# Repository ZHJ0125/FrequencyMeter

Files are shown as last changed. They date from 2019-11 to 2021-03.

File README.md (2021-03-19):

# FrequencyMeter
使用 Altium Designer 设计一款频率计

# Project Gallery
> 
> 1. Schematic
>

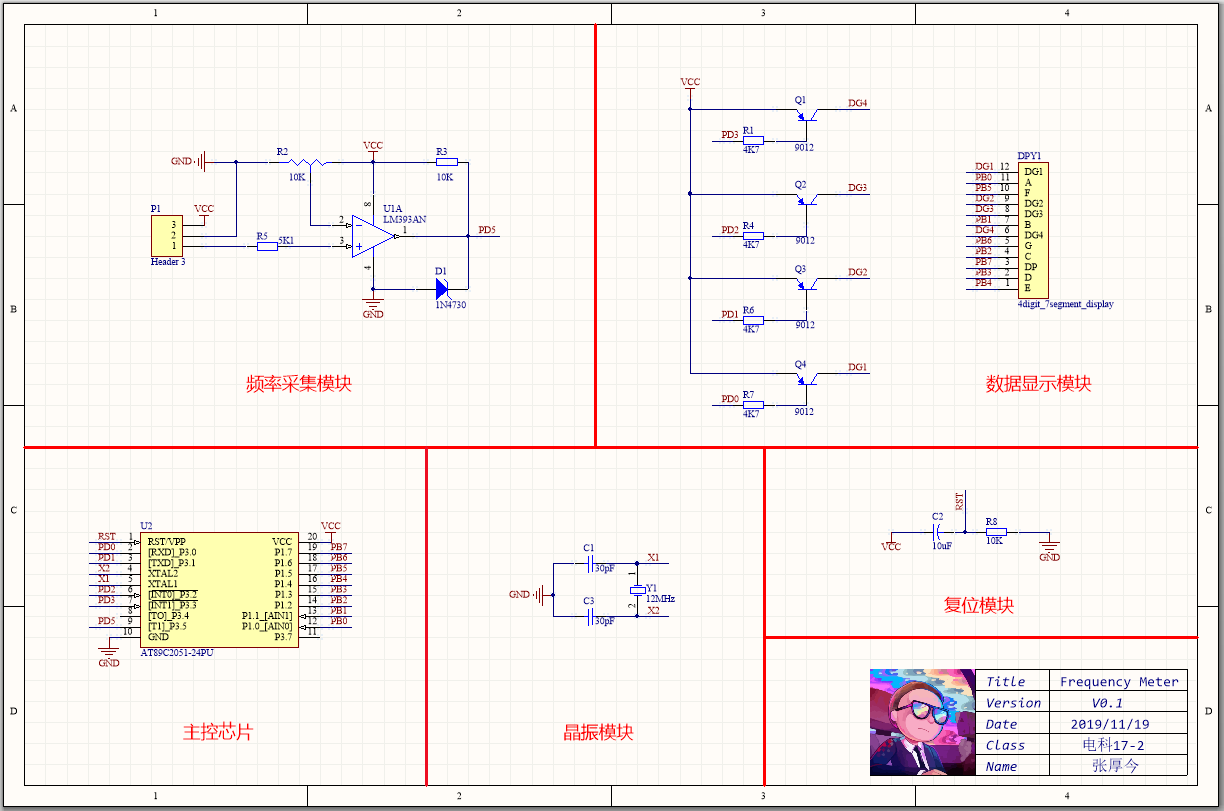
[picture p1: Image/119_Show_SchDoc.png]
119_Show_SchDoc


>
> 2. PCB Circuit
> 

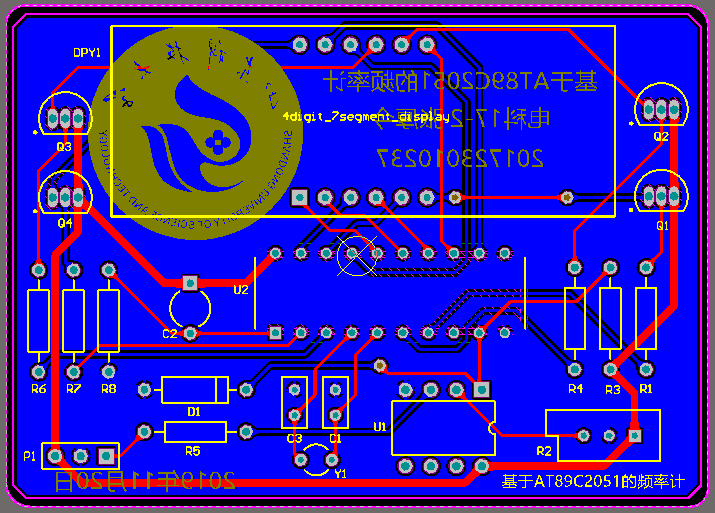
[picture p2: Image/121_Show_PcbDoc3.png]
121_Show_PcbDoc3


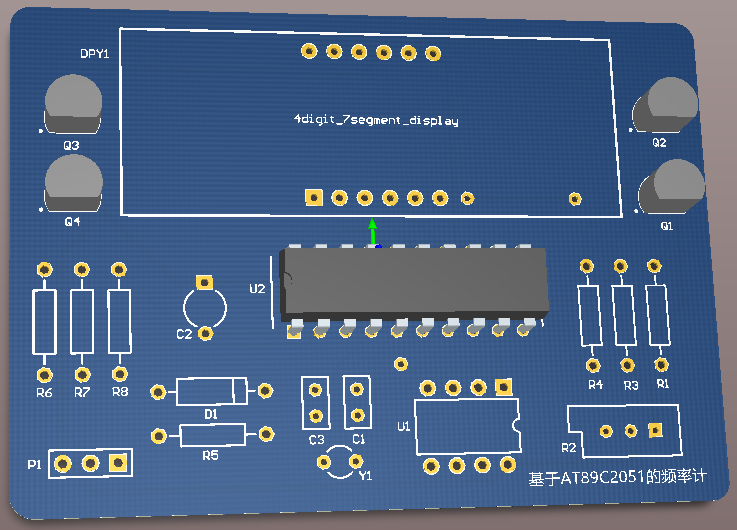
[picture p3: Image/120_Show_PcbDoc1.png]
120_Show_PcbDoc1


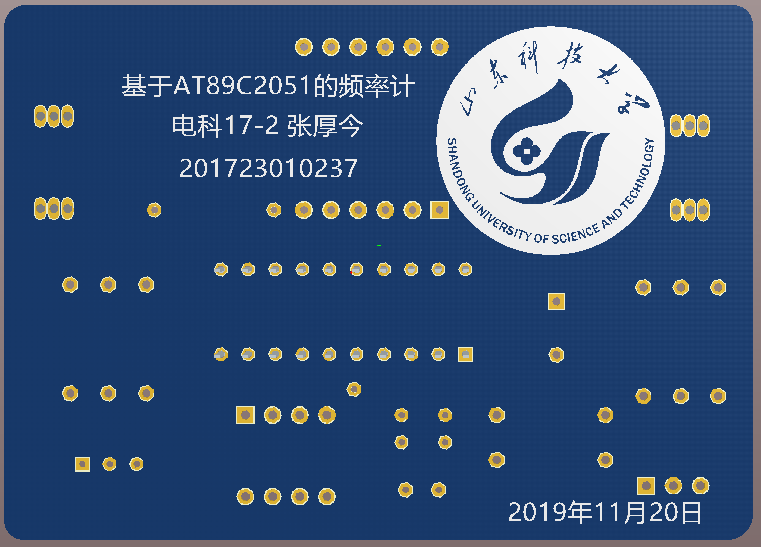
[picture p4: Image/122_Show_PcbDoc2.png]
122_Show_PcbDoc2


> 
> 3. Real object
> 

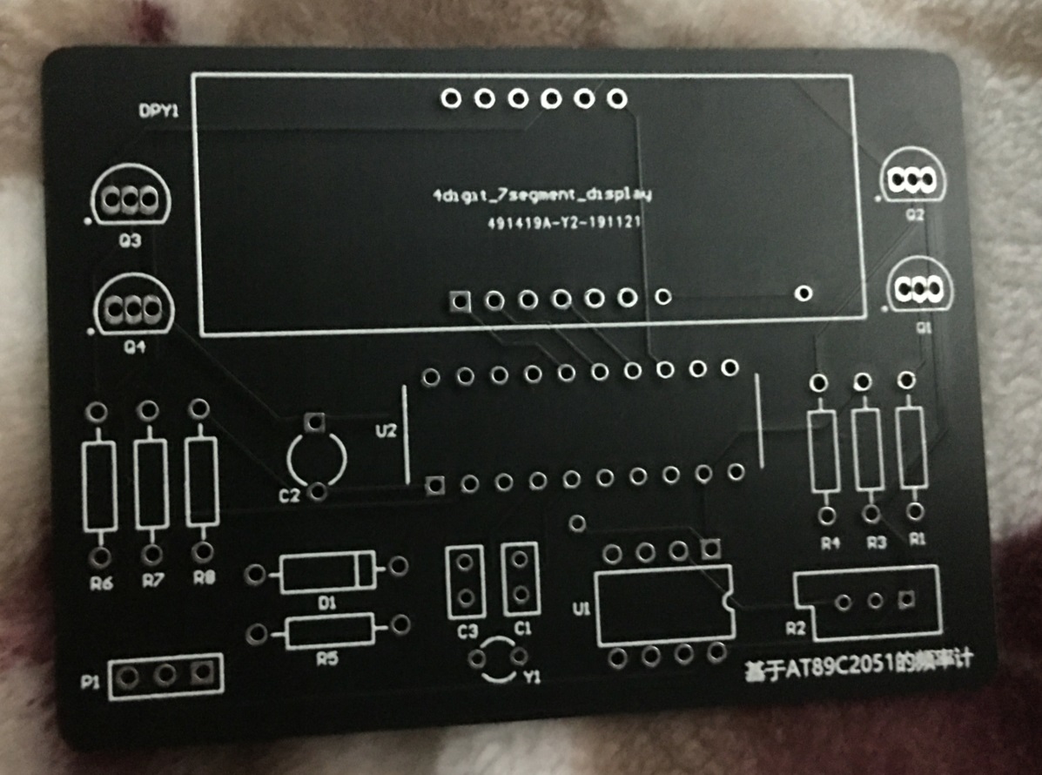
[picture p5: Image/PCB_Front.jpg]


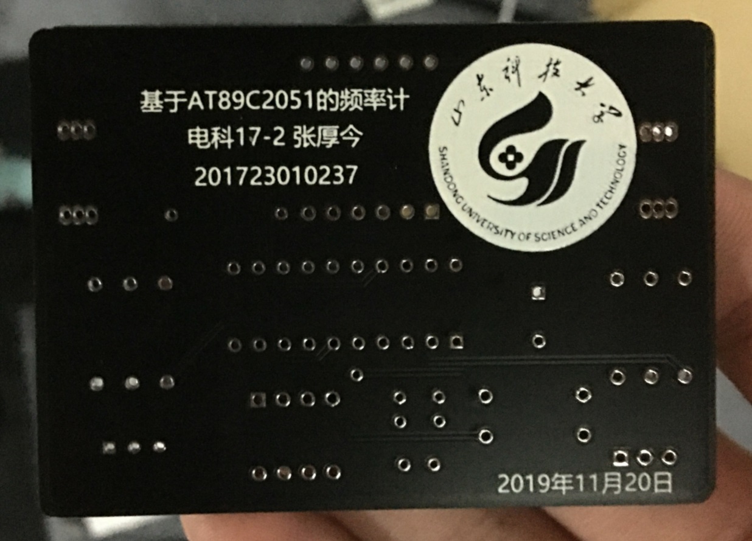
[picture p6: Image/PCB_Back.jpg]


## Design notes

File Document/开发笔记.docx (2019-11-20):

一、绘制原理图

1.1 新建工程

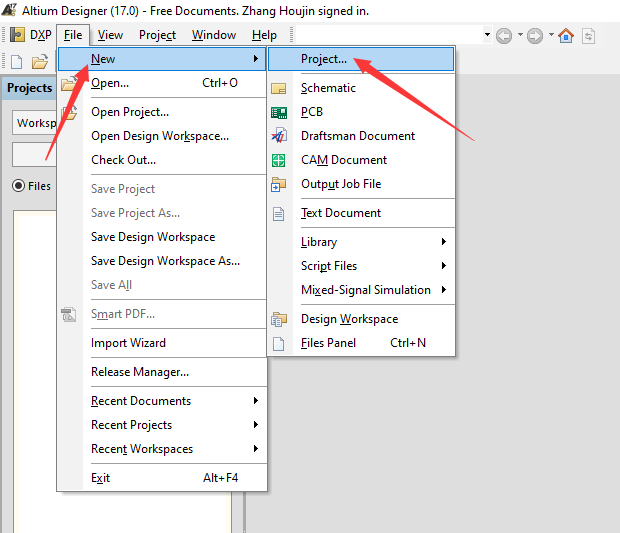
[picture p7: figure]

图1.1 新建项目

图1.2 新建工程文件

新建原理图文件

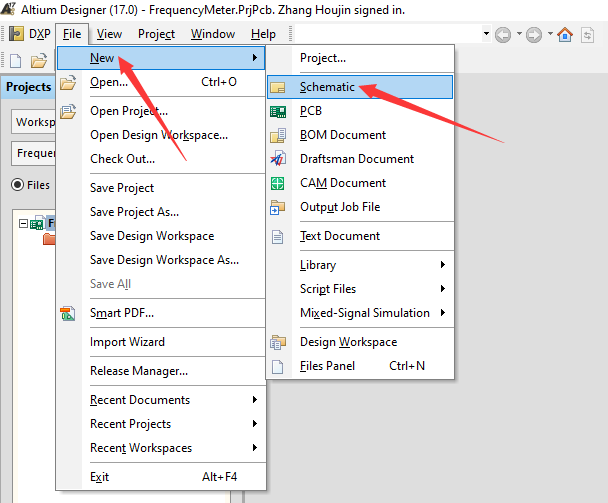
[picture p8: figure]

图1.3 创建原理图文件

图1.4原理图路径

1.2 绘制原理图

1.2.1 主控芯片

本次项目我准备全部使用网上下载的原理图库和PCB库，不再自己设计。因此首先去网上查找相关的库文件。

主控芯片使用AT89C2051芯片，20引脚，我在网上找了一些，但没有找到非常合适的，只找到了相似的.epw格式的元件库 (https://componentsearchengine.com/AT89C2051-24PU/Microchip)。Ewp格式原件经过格式转换 (https://www.samacsys.com/altium-designer-library-instructions/)即可得到AD软件可以使用的.SchLib原理图库和.PcbLib原件库。

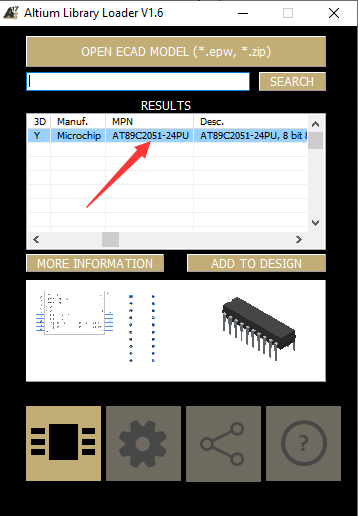
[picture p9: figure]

图1.5 文件格式转换

文件转换完成后，会在本地生成相应的库文件，里面包含此原件的原理图和封装。

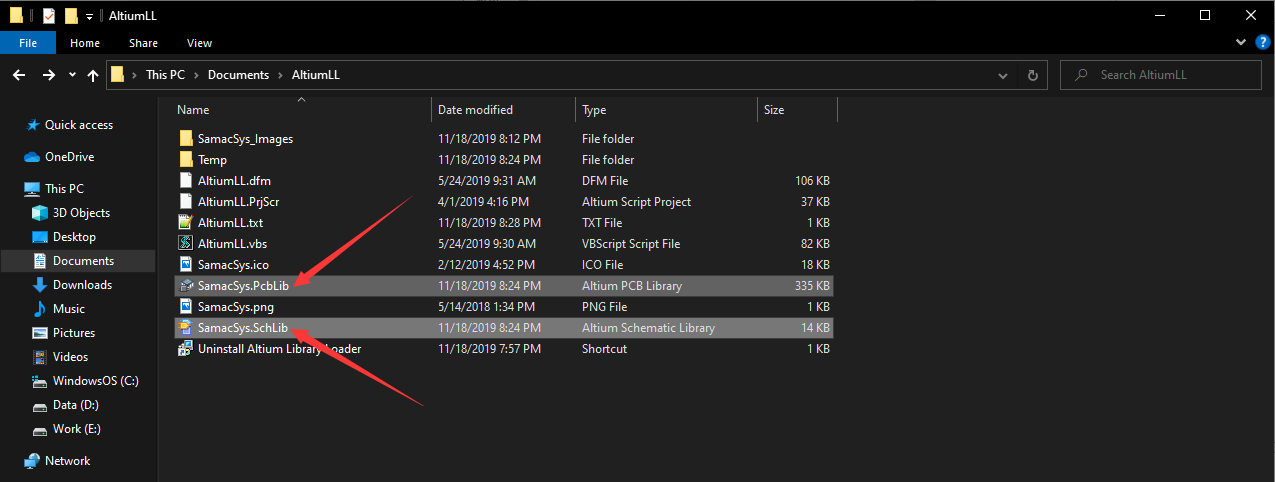
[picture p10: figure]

图1.6 原件封装库

现在把AT89C2051的原理图文件拖到原理图中就可以了。

1.2.2 数码管芯片

本次PCB使用到了四位一体数码管，我在网上找了很久都没找到合适的，于是决定自己画一个。先画原理图。

（1）原理图绘制

首先在原理图库中创建一个组件，命名为“4digit_7segment_display”。

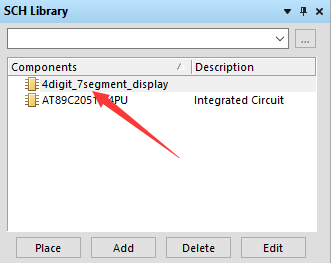
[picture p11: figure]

接着就是在编辑面板中画图了，画完之后长这样：

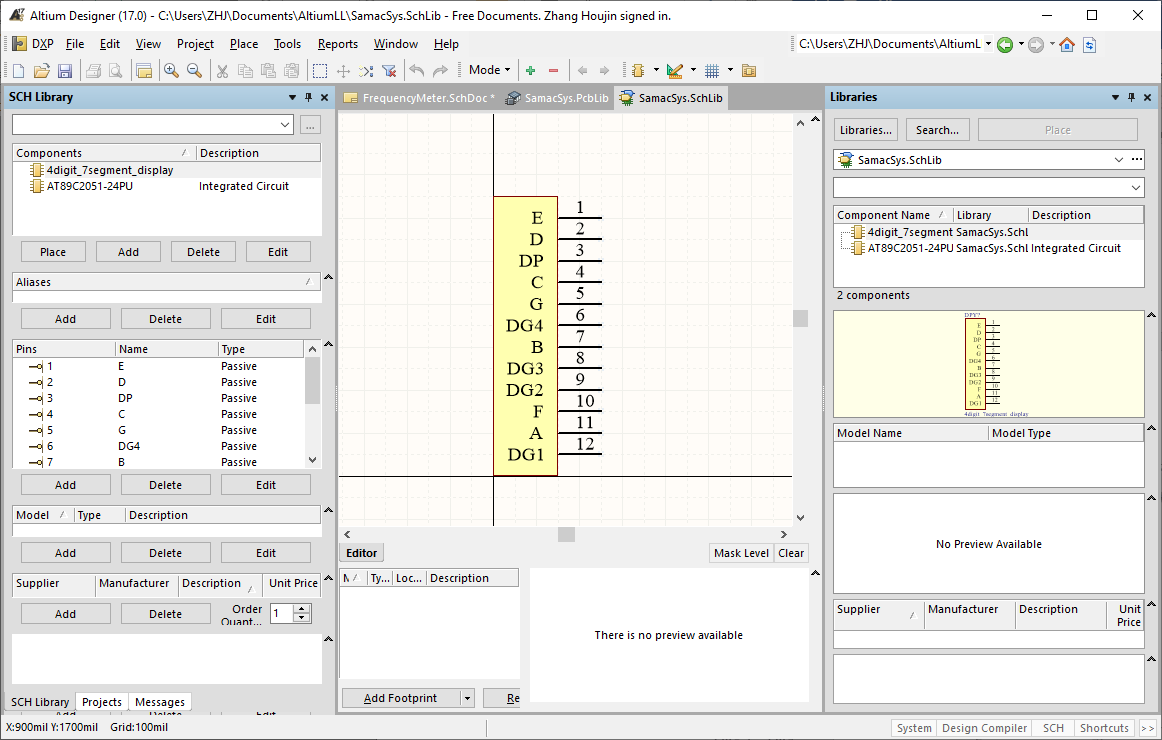
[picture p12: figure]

（2）封装库绘制

封装库的绘制参考课本9.4.2章节。首先收集相关的原件手册，在其中找的对应的封装标注。

按照此封装的标注，进行原件封装的绘制。首先设置单位为公制单位。

打开原理图设置界面，在units页面选择使用公制单位系统。

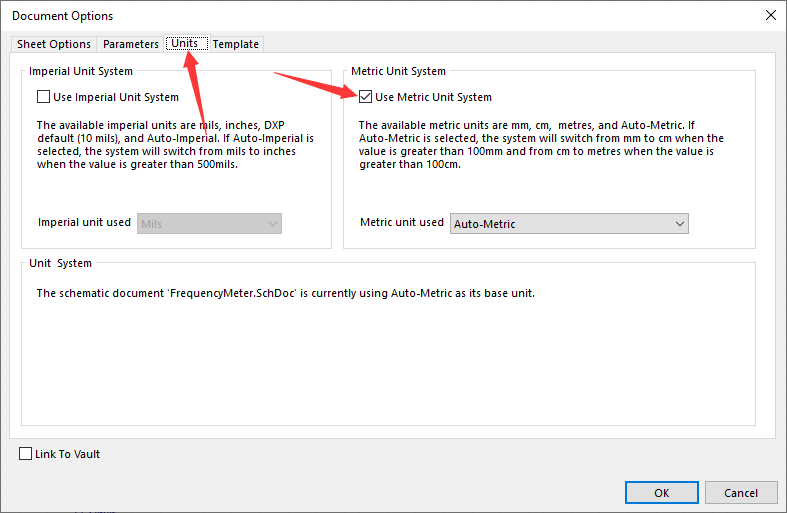
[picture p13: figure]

接下来绘制原件的外形轮廓，根据之前的原件封装，可以计算出该原件的矩形轮廓的范围。如果以该原件的中心点为坐标原点，则可以计算出矩形轮廓的四个顶点坐标：(-25.1,9.5)、(25.1,9.5)、(-25.1,-9.5)、(-25.1,-9.5)。实际绘图中，要比这些点的数值稍大一些。同样在原理图库中添加一个新的原件，命名为“4digit_7segment_display”。

接着重命名数码管封装

下面开始绘制数码管封装。

1. 切换当前层为丝印层

2. 绘制矩形边框

首先点击放置，选择直线。

之后绘制矩形上边直线，通过设置线的起始和终止位置实现该线的绘制。

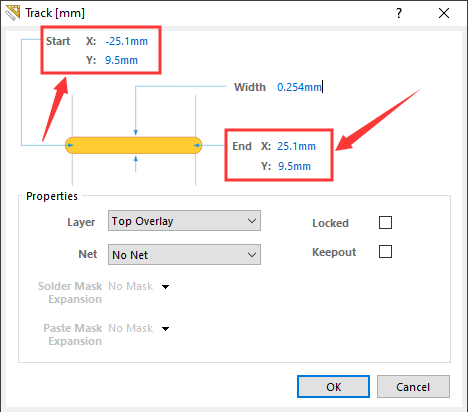
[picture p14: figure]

其余三根线使用同样的方法绘制，绘制完成后如下图所示。

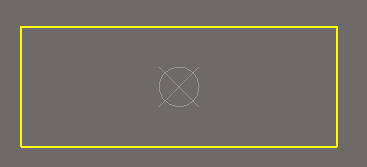
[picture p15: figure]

为了美观，接下来放置一个字符串表示四位一体数码管。

接下来放置焊盘。首先要计算焊盘的绝对位置，下面我根据课本的数据进行绘制。

按下Tab键设置焊盘的属性，首先确定一号焊盘的属性。

之后，按照一号焊盘的规则，放置剩余的十一个焊盘。

接下来保存该文件即可。下面需要将该原件的原理图与封装关联起来。先找到它的原理图，点击下方“Add Footprint”按钮添加封装文件。

找到刚才画完的封装文件，添加关联即可。

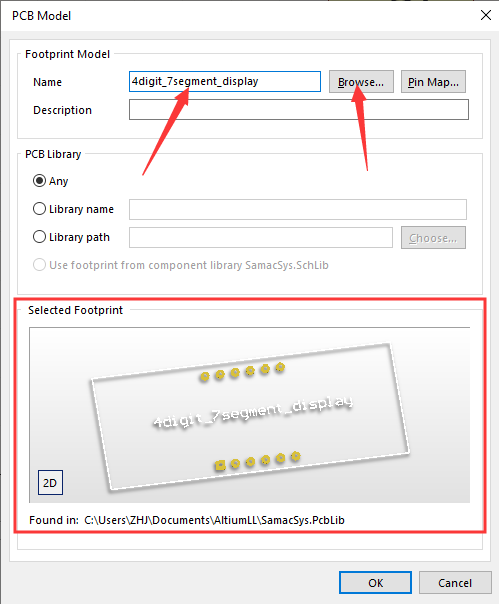
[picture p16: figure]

关联成功后可以看到原理图所关联的封装文件。

现在四位一体数码管的封装库就做好了。

1.2.3 运算放大器

本次工程中使用到的运放型号为LM393AN，在“Motorola Analog Comparator.IntLib”有该原件的原理图。下载该元件库，直接导入该原件即可。

运放被分为两个部分，本次将会使用partA部分。

1.2.4 稳压二极管

课本原理图中的稳压二极管使用的是1N4730，这里我使用了“Miscellaneous Devices.IntLib”元件库中的齐纳二极管代替。

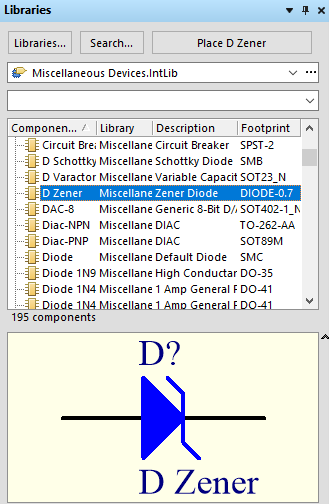
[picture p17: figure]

1.2.5 其他原件

其他原件算是比较常规的原件了，所以不再详细说明。按照原理图找到相应的原件并放置到面板上即可。

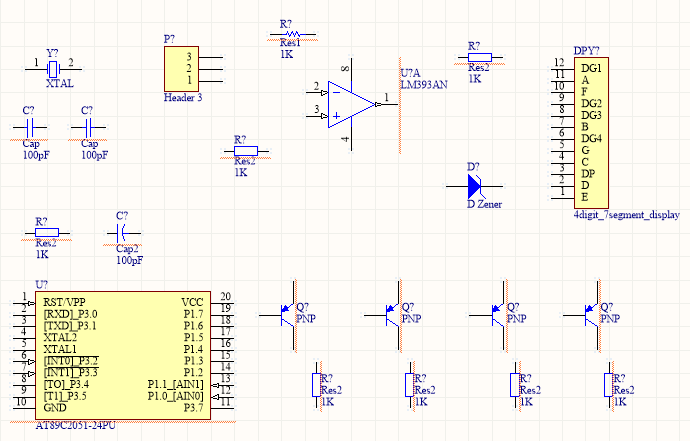
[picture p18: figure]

1.2.6 原理图连线

按照课本的原理图示例，连接各个原件。

接下来进行原件描述的改写。按照课本的示例，改写各元件的描述。

接下来需要生成每个元件的网络标号，使用AD的工具自动生成即可。

打开网络标号生成界面，设置好标号排布方式，点击更新列表。

之后点击接受这些改变，会弹出预改变原件的对话框，点击验证更新以检查元件封装是否正确。如果没有问题，点击执行更改按钮即可完成更新。

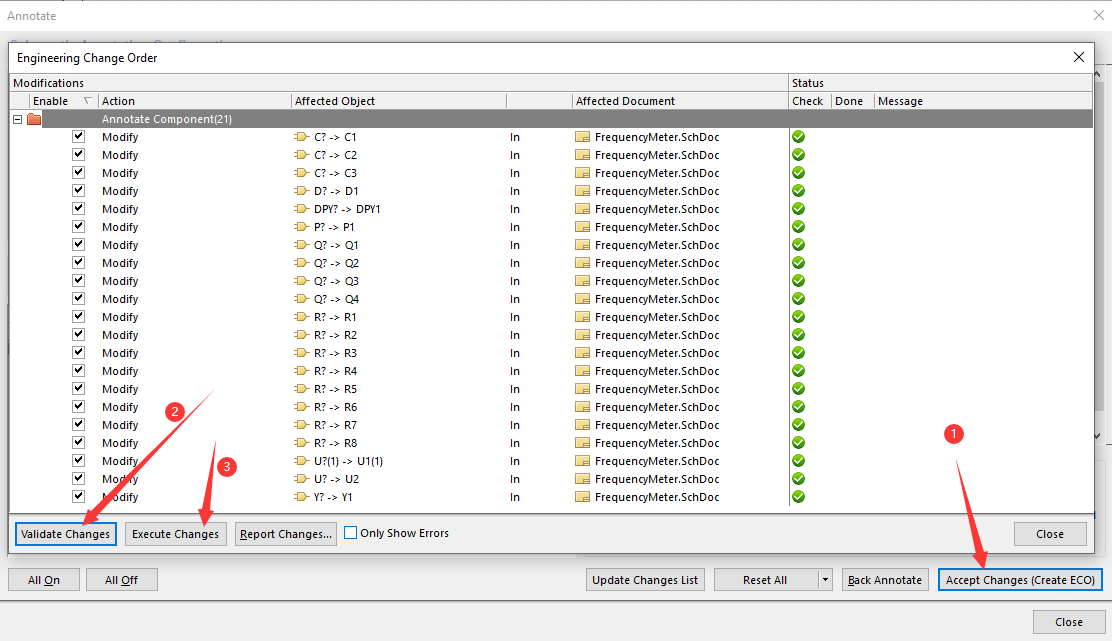
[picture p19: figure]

现在，原理图已经完成标号了。

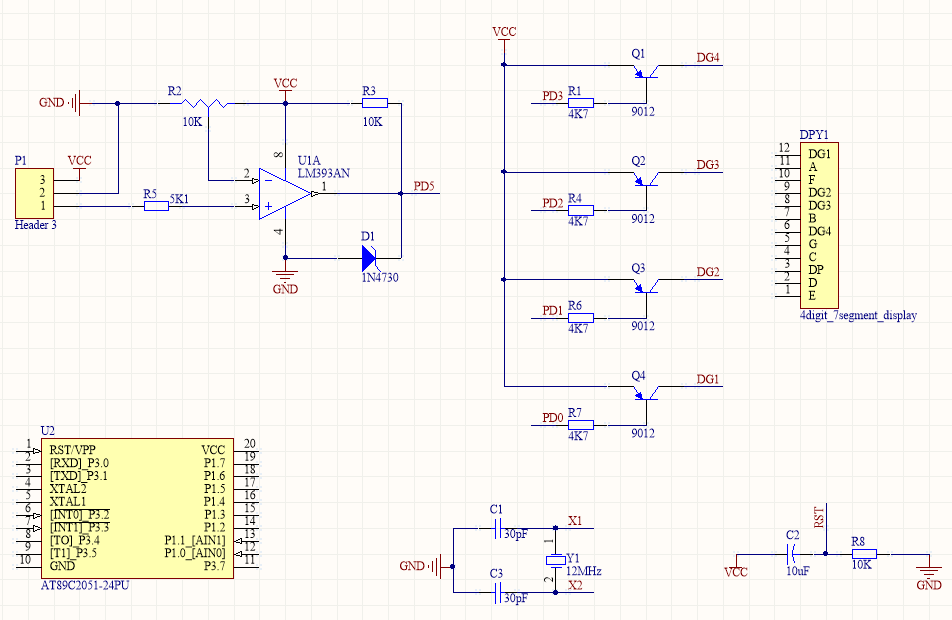
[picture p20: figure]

1.2.7 编译检查

原理图绘制完成后，需要首先进行编译检查。

编译完成后，软件会在message界面给出很多错误和警告信息（如果有问题的话）。下面就需要针对这些错误信息对原理图进行修改。

我这里一共有47处错误信息，首先看第一项：

这是那个运算放大器，他警告说组件B没有使用。因为这个运放是LM393AN原件的一部分，我们只用了这一部分的原件，所以该警告可以忽略。

第二项报错：

错误二提示，网络标号为DG1的网络，只有一个引脚。去原理图中看一下，发现果然有问题：我忘画主控芯片和数码管的网络标号了。马上修改原理图，重新编译后，错误信息已经没有了，剩下了29个警告信息。再经过我的修改，现在剩下了11个警告信息。大部分警告信息是因为没有驱动源或者原件没有对齐网格导致的，对原理图功能没有影响，所以这些警告可以忽略。

1.2.7 原理图修饰

原理图绘制完成后，需要对其进行相关问题说明和修饰。首先创建图纸模板，将必要的信息填写到模板中。之后将原理图各部分模块进行区分，标注并说明各模块内容。

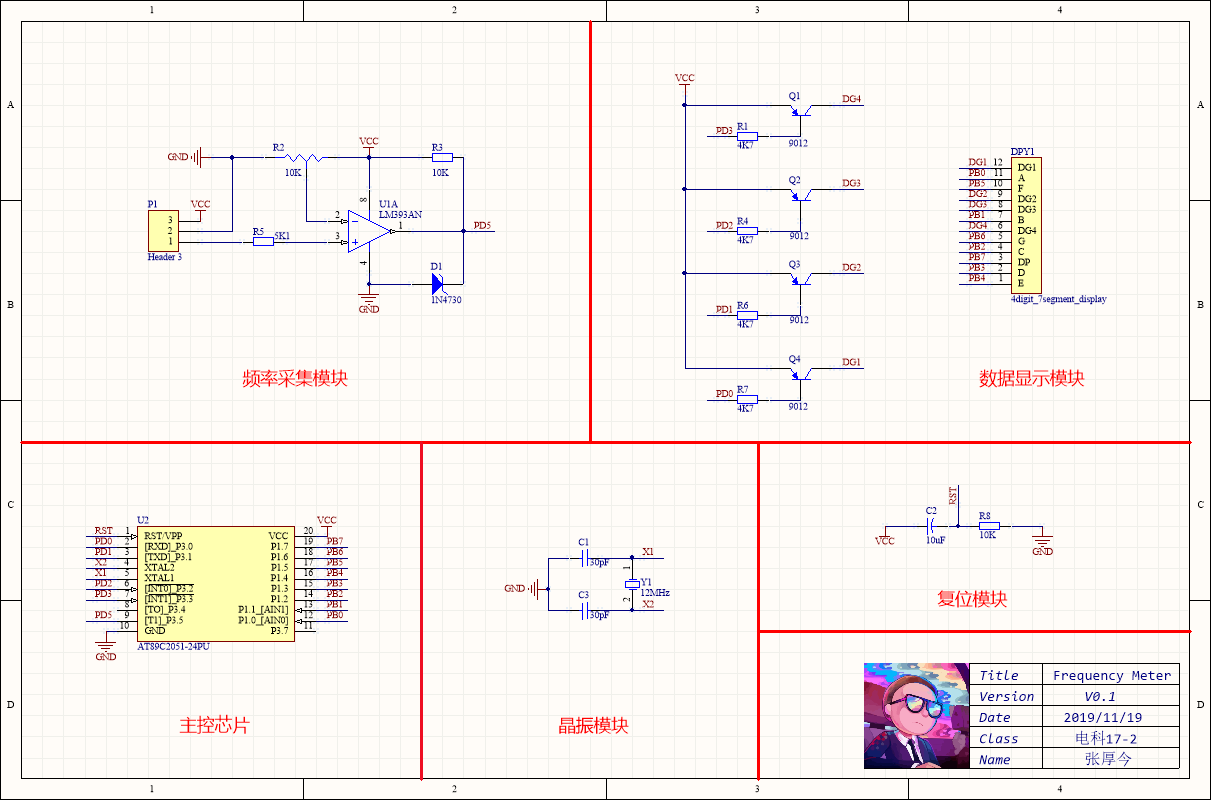
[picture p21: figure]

二、绘制PCB

2.1 新建PCB文件

首先在本工程目录下创建新的PCB文件。

另存PCB文件，同时重命名为FrequencyMeter.PcbDoc

2.2 绘制PCB的准备

绘制原理图前，需要查看当前的封装是否合适。在原理图编辑界面查看工具菜单下的封装管理界面。

进入封装管理界面，查看各个元件的封装。

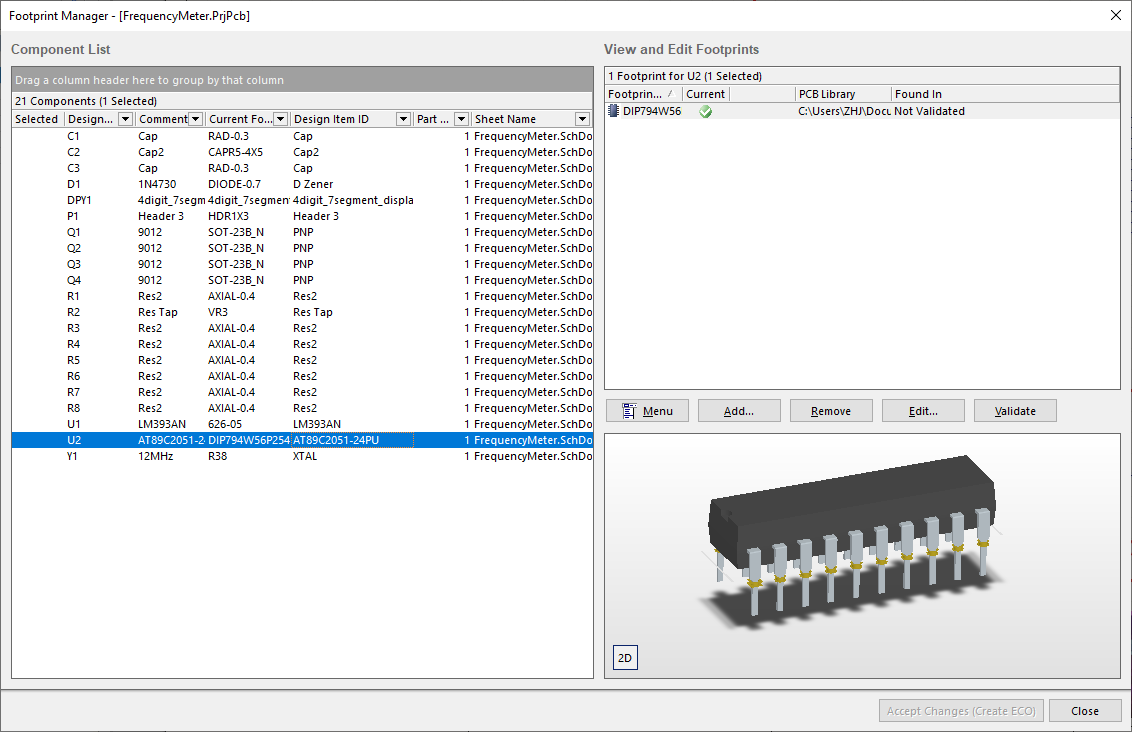
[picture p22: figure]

2.3 导入PCB

现在根据原理图将原件的封装导入OCB文件中。在原理图界面的设计菜单中，选择更新原理图至PCB文件。

之后会弹出预更改窗口，点击验证改变以验证封装的正确性。之后点击执行更改，将封装导入PCB文件中。

这样，元件的封装就可以导入到PCB文件中了。

2.3 设置规则

PCB绘制过程最重要的就是规则的制定，下面需要进行PCB布线规则的改写。在PCB绘制界面打开规则设置。

（1）电器规则

电器规则包括安全距离、短路规则、未布线网络、未连接的引脚等规则。首先设置安全距离，将安全距离设置为10mil。任何网络线之间都不能小于10mil的安全距离，否则就会报错。

其他规则设置为：不允许短路、不检查未连接网络，默认即可。

（2）布线规则

布线规则包括走线宽度、布线拓扑、布线优先级、布线工作层、布线拐角模式、布线过孔类型、布线扇形控制、差分线设计，下面逐步进行设置。

1. 走线宽度

根据课本的建议，信号线的宽度在10~15mil左右，电源线的宽度大约30mil~50mil，那么我就设计两套规则：“默认线宽”在10~50mil，推荐线宽设置为12mil作为信号线默认线宽；“电源线线宽”设置为30~50mil，推荐线宽设置为30mil作为电源线的默认线宽。

首先修改默认线宽：

之后添加一个地线的线宽规则：

这里设置默认地线宽度为30mil，线宽范围为30mil~50mil。电源线VCC以相同的规则进行设置。下面要设置规则的优先级，将电源线和地线的优先级设置为高优先级，全局布线规则设置为低优先级。

2）拓扑结构

拓扑结构的设置对于自动布线有重要的作用，但是对于手动布线没有太大作用。拓扑结构设置为默认的最短方式。

3）布线拐角模式

布线拐角模式是在布线拐角时默认的拐弯方式，系统默认的方式是45度拐角，还有90°拐角以及圆角的方式。我设置的是45°默认拐角。

至于其他的规则，因为我没有特殊的要求，所以就设置为默认的选项就可以了。

2.4 原件封装检查

在进行PCB绘制之前，需要首先进行原件的封装检查。以课本的封装为标准，核对我的PCB封装是否正确。经过检查发现，我的四个三极管、一个电位器、两个电容和一个稳压二极管的封装是与课本上不同的。一共八个封装有问题，所以现在就需要改一下封装。

现在开始修改原件的封装。以三极管Q4为例，双击该封装，打开元件设置。在footprint选项中点击按钮修改封装样式。

打开封装窗口，选择与课本相同的封装样式。

我选择的是TO-226-AA封装的三极管。下面将剩余的七个封装修改过来即可。改过来之后，需要更新一下PCB工程。

更改之后，原理图上原件对应的封装就更新成刚刚设置的封装了。所有元件封装之后，如下图所示。

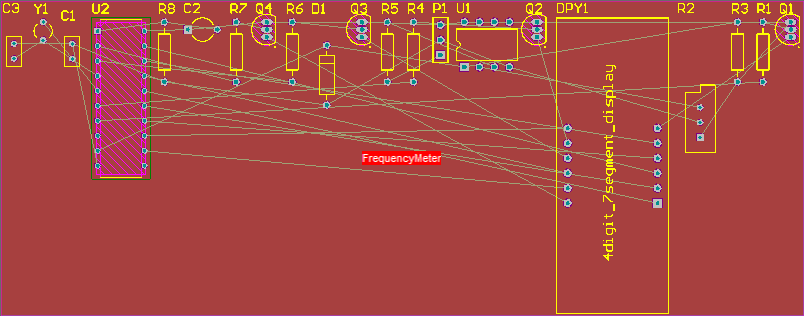
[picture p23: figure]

2.5 规划轮廓

规则设置好了之后，需要首先设计PCB的整体轮廓。首先将PCB的规格单位设置为公制单位，然后画出一个70mm×50mm的矩形框，作为PCB的外部轮廓。

先重新设置PCB的原点：

在PCB中放置原点，然后在机械层画一个70*50的矩形。绘制方法就是先随便画一条线段，然后设置线的起始位置和终止位置。四条线可以使用相似的方式画出来。

为了更加美观，我将矩形的四个角都做了倒角处理。

现在重新定义板子形状：

定义完成后，板子形状就变成了经过倒角的矩形。

2.6 元件布局

PCB轮廓定义完成后，就可以开始进行元件布局了。按照原件尺寸进行布局，这里还需要考虑原件的大小形状以及相对位置，避免元件之间发生碰撞，还需要考虑是否便于焊接，是否符合使用习惯等等因素。下面我按照课本的示例开始布局。

在布局之前，先在禁止布线层画一个框，以便日后在布线时不再添加。

下面开始进行原件布局。

初步的PCB布局如上图所示。

下面首先来调整一下丝印的大小和位置。

查找所有丝印，调整他们的大小。

这样所有丝印的文字就已经被选中了，现在修改丝印文字大小为6mil×30mil

现在所有丝印文字都变成6mil×30mil了。重新调整一下丝印布局即可。

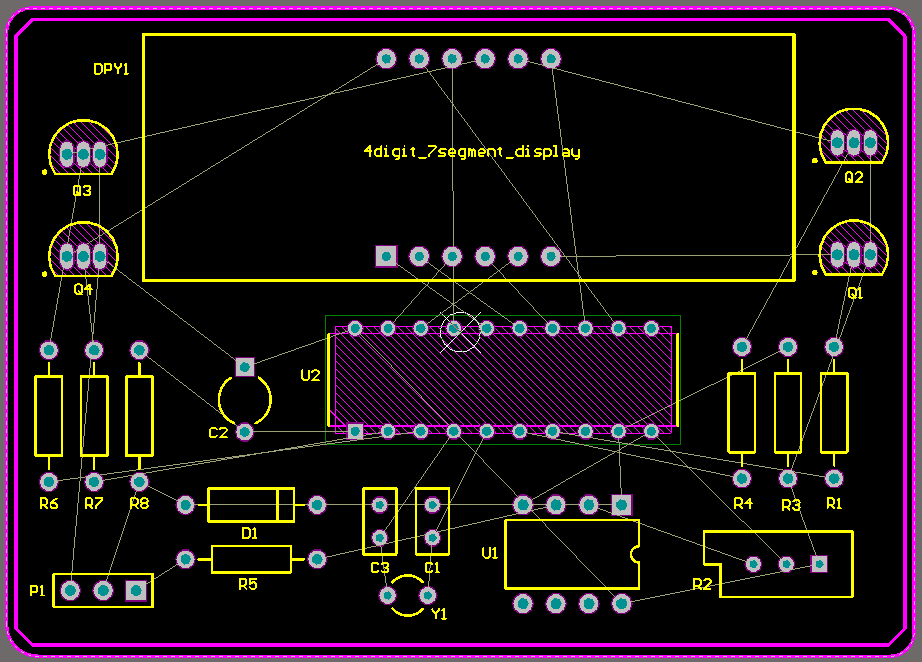
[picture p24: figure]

上面图中是丝印修改完成后的PCB布局。

2.7 原件连线

首先绘制VCC和GND的连线。

然后在顶层绘制其它信号线。

顶层信号线布局如上图所示，接下来在底层继续绘制还未连接的信号线。

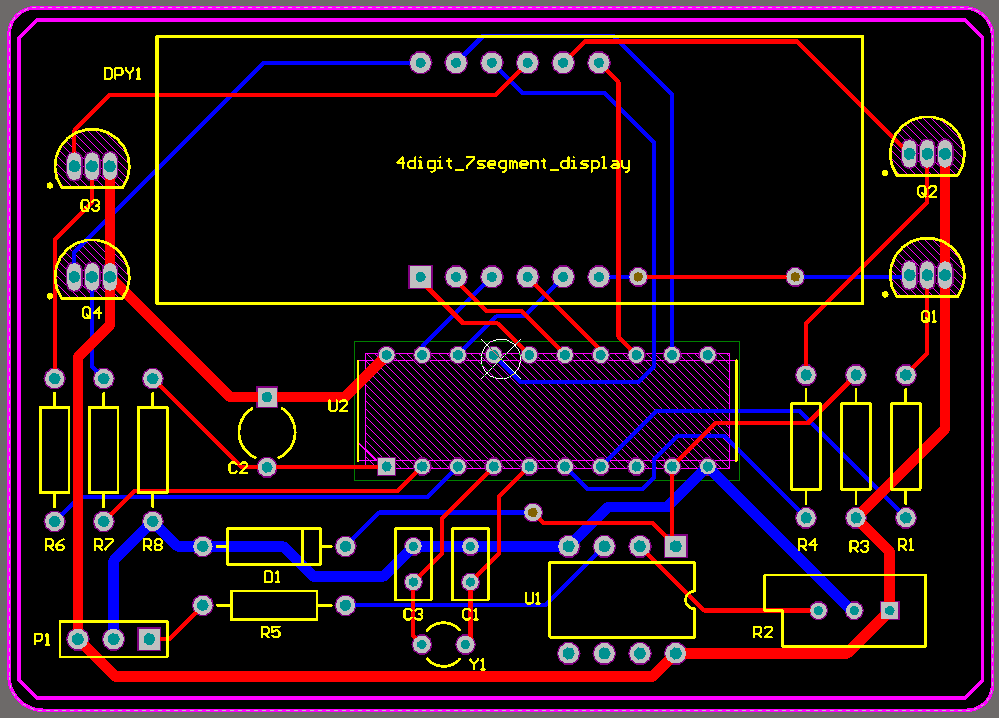
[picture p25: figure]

在连接底层信号线时，有三处使用了过孔。最终信号线布局如上图所示。

2.8 DRC检查

PCB原件连接完成后，首先进行一次DRC检查。

打开DRC检查窗口

运行设计规则检查后，我的PCB被检查出有24处违反规则。

现在逐一排查这些错误，先看第一个。

双击该错误，将会跳转到PCB对应的位置。

这个报错的意思是说：这两个阻焊层之间的间距是2.63mil，小于最小规则间距10mil，所以报错。这个地方应该不算大问题，可以直接忽略。为了使其不在报错，可以修改DRC检查的规则。

因为之前看到阻焊之间的距离是2.63mil，所以我将规则的最小距离设置为2.5mil。更改完成后再次进行DRC检查。

可以看到，错误已经减少到了16处。下面继续进行PCB调试。

以这16处错误中的一处为例，其报错信息如下。

在PCB中的错误定位如下：

可以看到，错误原因是：丝印到阻焊之间的距离小于规则的最小间距。于是继续修改PCB规则。

我将最小规则间距设置为8mil，然后再次进行DRC检查。

好了，现在DRC检查通过了。

2.9 铺铜和补泪滴

为了减小PCB信号之间的干扰，更好地发挥PCB性能，需要给PCB进行覆铜处理。在铺铜之前，先进行一个补泪滴操作，目的是使焊盘和信号线之间能够更好地连接。

打开泪滴菜单

选择默认的选项即可。补泪滴完成后，界面会自动生成泪滴的信息报表。

补泪滴结束后，进行覆铜操作。

打开覆铜界面

选择在底层覆铜，连接到GND网络，同时去除死铜。

接下来就是选择覆铜区域，直接选择整块版就可以了。

覆铜结束后的效果如下图所示：

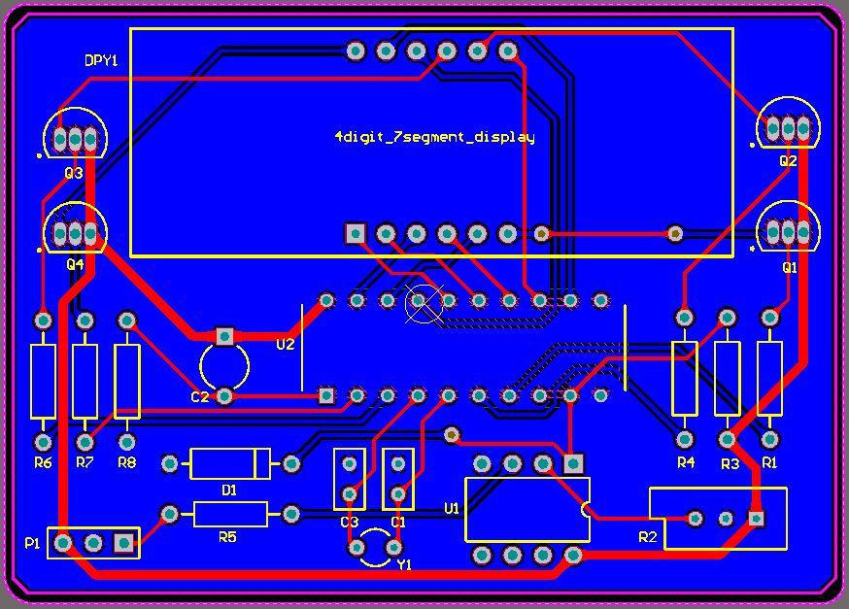
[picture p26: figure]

因为只有底层有覆铜，所以整块板子呈现大片蓝色。顶层的红线是VCC和一些顶层的信号线。

保险起见，需要再次进行一次DRC检查，确保PCB覆铜之后没有问题。我进行DRC检查后没有问题。

2.10 添加丝印

在PCB上添加丝印可以帮助我们了解该PCB的功能、设计时间等信息。首先找到一块合适的位置，添加一些字符串表明该PCB的功能信息以及制作信息。我在PCB的右下角添加了PCB名称。

下面我想往PCB中添加一个图片，需要运行一个AD脚本，创建图标。

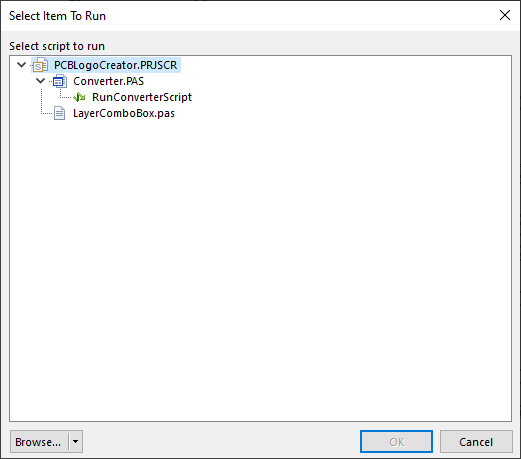
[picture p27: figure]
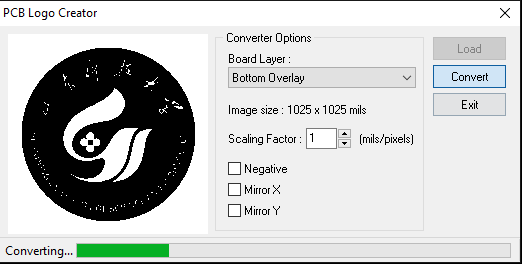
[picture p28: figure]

图片转换完成后，在底层添加该logo，同时添加我的个人信息。

注意这里的字符串和图片都需要是经过镜像的，因为这是我们以前面的视角观察底层的视图。实际的背面效果如下图所示：

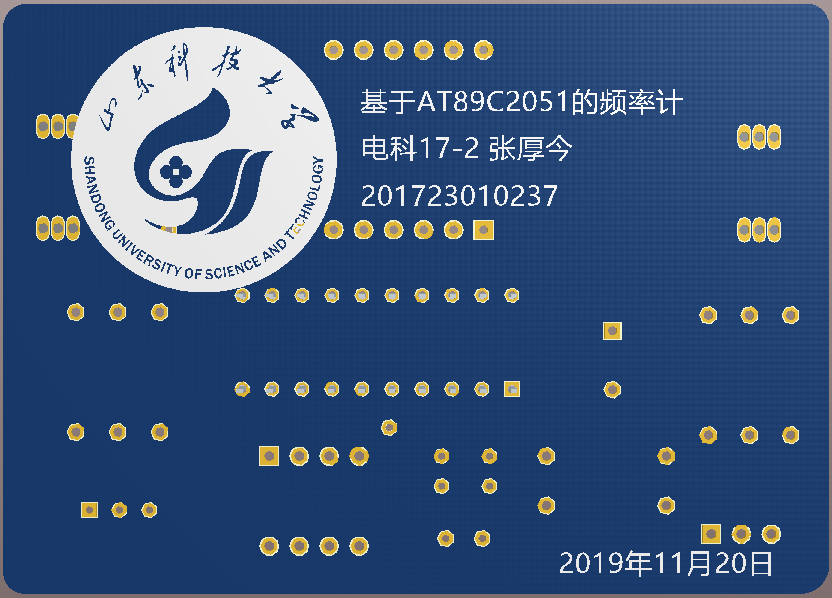
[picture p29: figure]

实际的前面效果：

这里我进行了一次DRC检查，发现有95处错误。错误原因是那个图片logo放到焊盘上面了，丝印与焊盘之间的间距太小，所以报错了。为了避免图片丝印覆盖焊盘，我将图片的大小和位置进行了调整，最终得到以下设计：

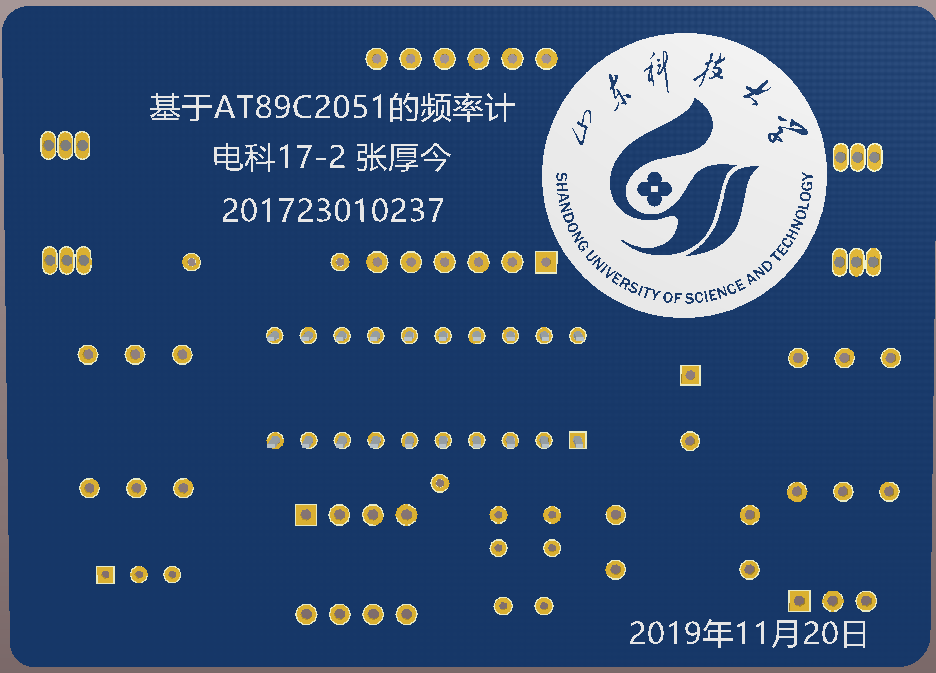
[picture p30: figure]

再进行DRC检查，不再报错。

2.11 生成工程文件

首先利用smart PDF生成PDF文件

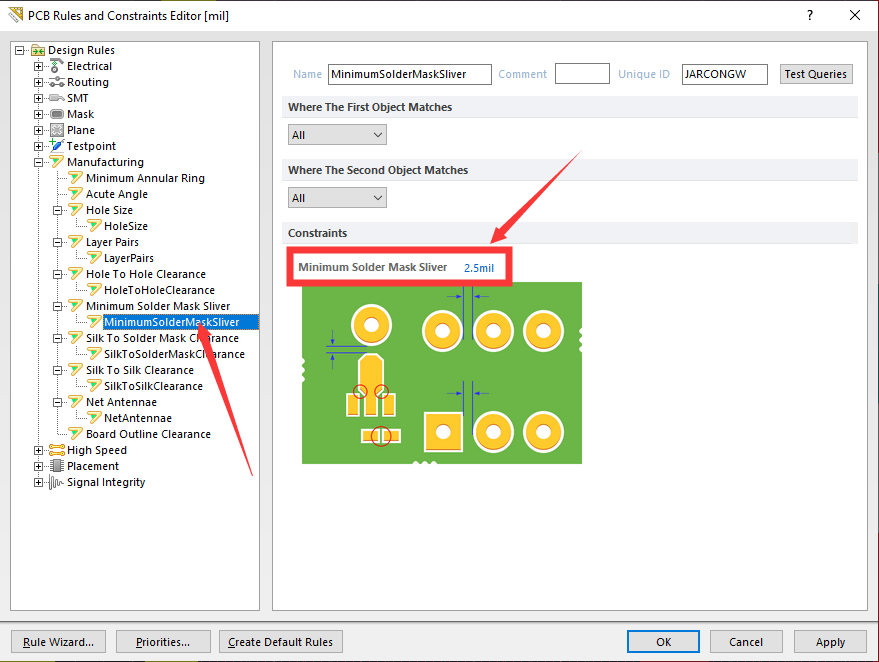
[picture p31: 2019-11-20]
Image/76_修改DRC阻焊规则.png

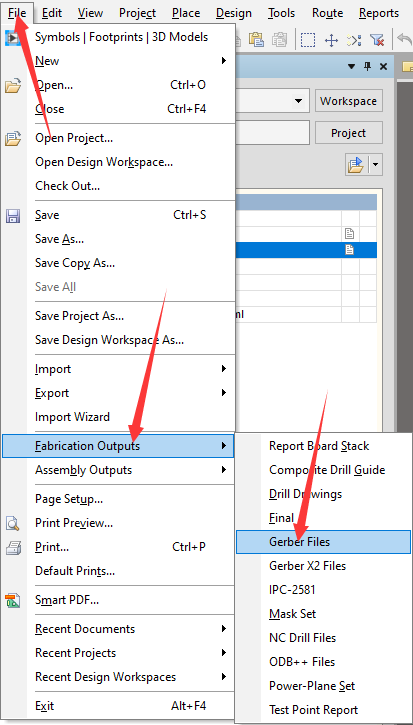
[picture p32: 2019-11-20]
Image/97_Gerber文件生成.png

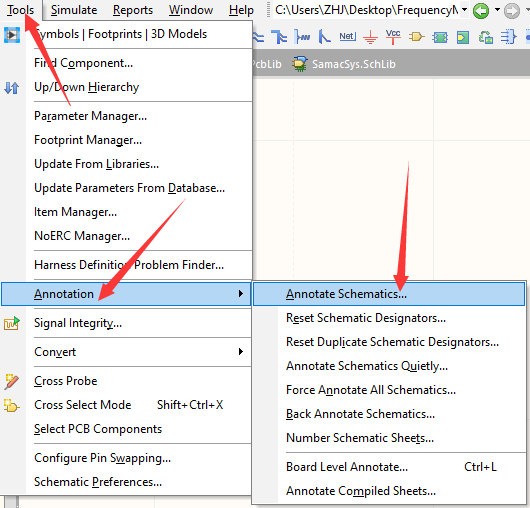
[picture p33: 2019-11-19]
Image/31_绘制原理图.png

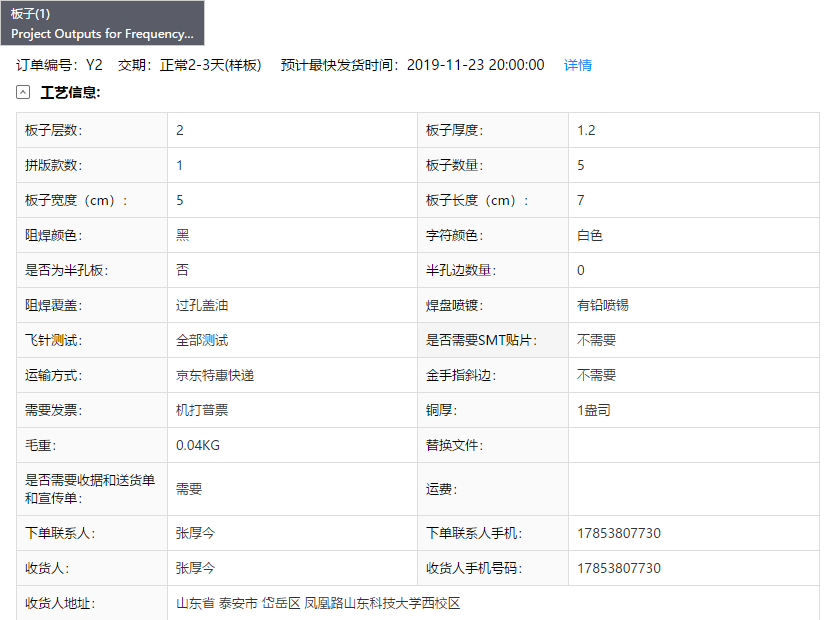
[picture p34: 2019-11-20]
Image/115_订单详情.png

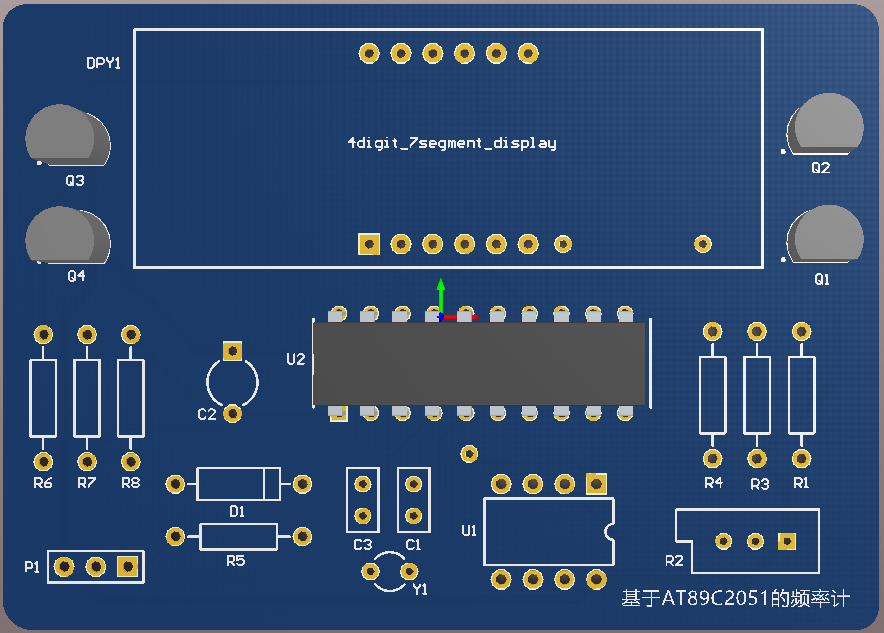
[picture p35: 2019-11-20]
Image/92_实际前面效果.png

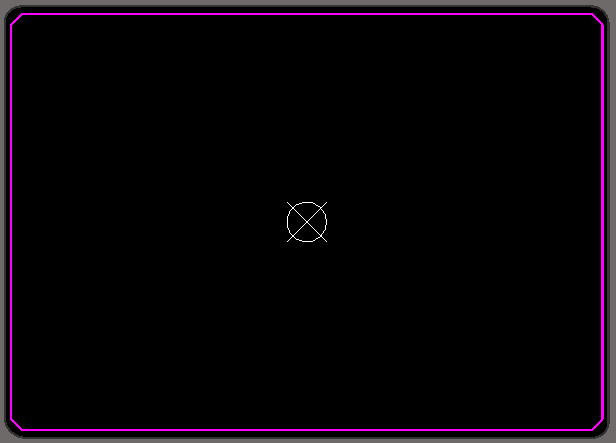
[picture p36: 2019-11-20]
Image/63_禁止布线层.png

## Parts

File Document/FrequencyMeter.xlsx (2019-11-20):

Comment | Description | Designator | Footprint | LibRef | Quantity | Value
Cap | Capacitor | C1, C3 | RAD-0.1 | Cap | 2 | 30pF
Cap2 | Capacitor | C2 | CAPR5-4X5 | Cap2 | 1 | 10uF
1N4730 | Zener Diode | D1 | DIODE-0.4 | D Zener | 1
4digit_7segment_display |  | DPY1 | 4digit_7segment_display | 4digit_7segment_display | 1
Header 3 | Header, 3-Pin | P1 | HDR1X3 | Header 3 | 1
9012 | PNP Bipolar Transistor | Q1, Q2, Q3, Q4 | TO-226-AA | PNP | 4
Res2 | Resistor | R1, R3, R4, R5, R6, R7, R8 | AXIAL-0.4 | Res2 | 7 | 4K7, 10K, 4K7, 5K1, 4K7, 4K7, 10K
Res Tap | Tapped Resistor | R2 | VR5 | Res Tap | 1 | 10K
LM393AN | Dual Comparator | U1 | 626-05 | LM393AN | 1
AT89C2051-24PU | Integrated Circuit | U2 | DIP794W56P254L2591H533Q20N | AT89C2051-24PU | 1
12MHz | Crystal Oscillator | Y1 | R38 | XTAL | 1

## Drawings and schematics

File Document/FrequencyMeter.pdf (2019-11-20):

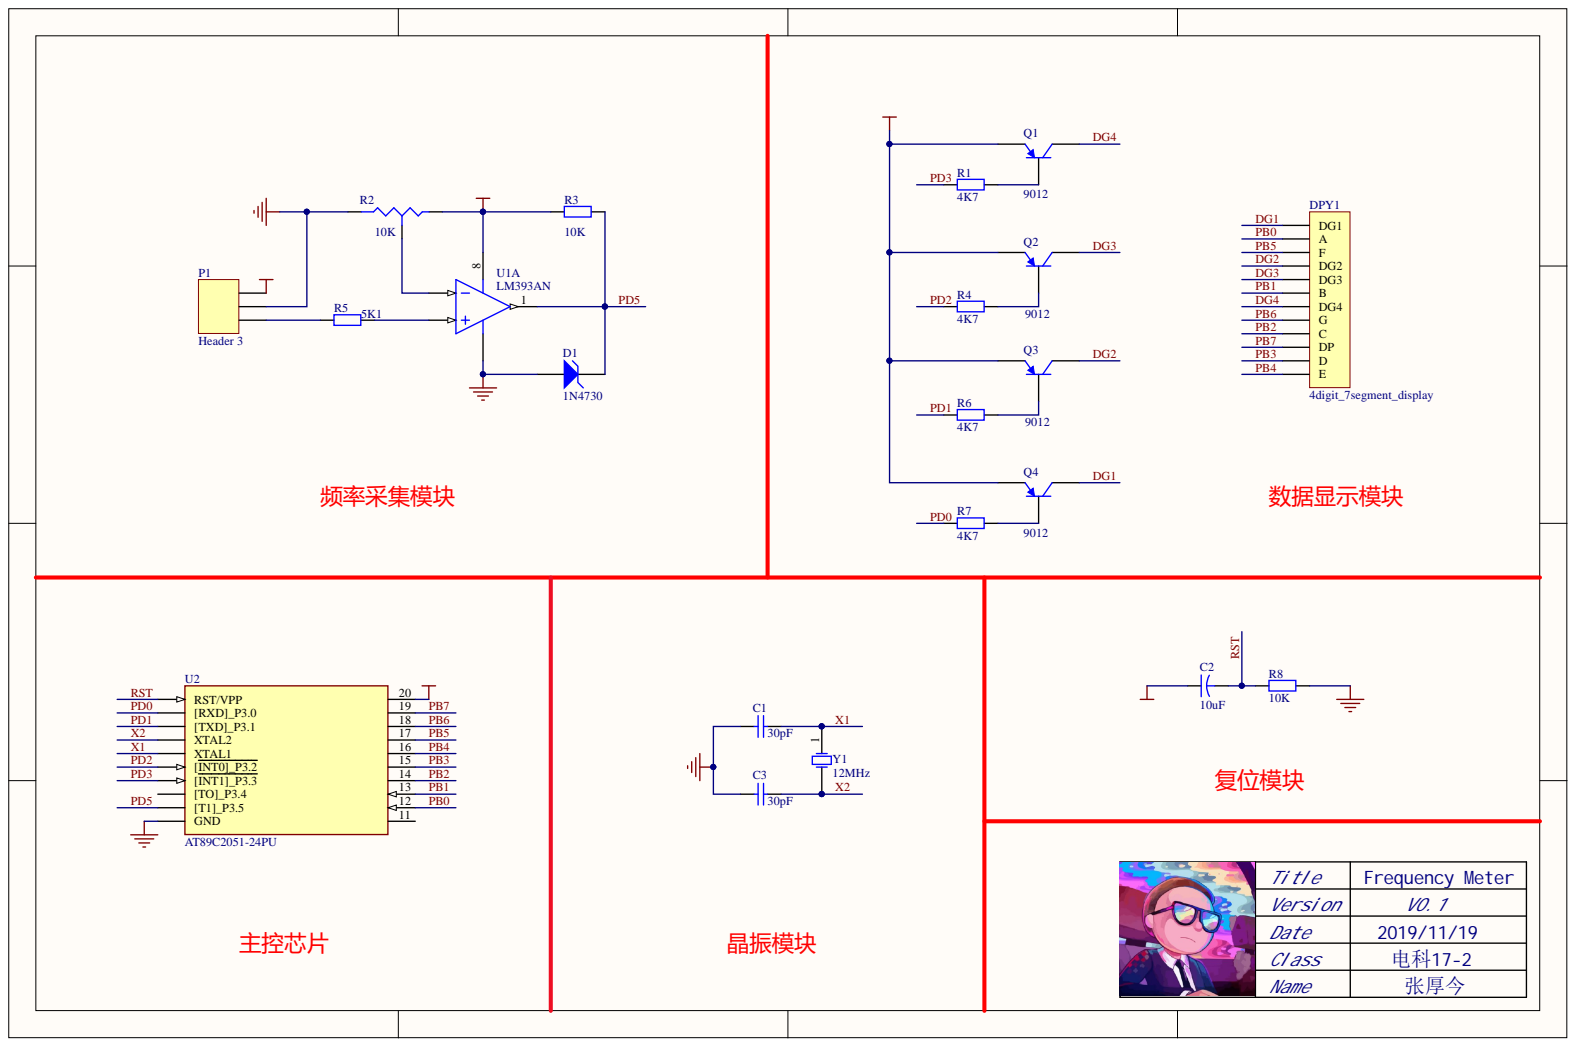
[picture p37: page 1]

Title | Frequency Meter
Version | V0.1
Date | 2019/11/19
Class | 电科17-2
Name | 张厚今

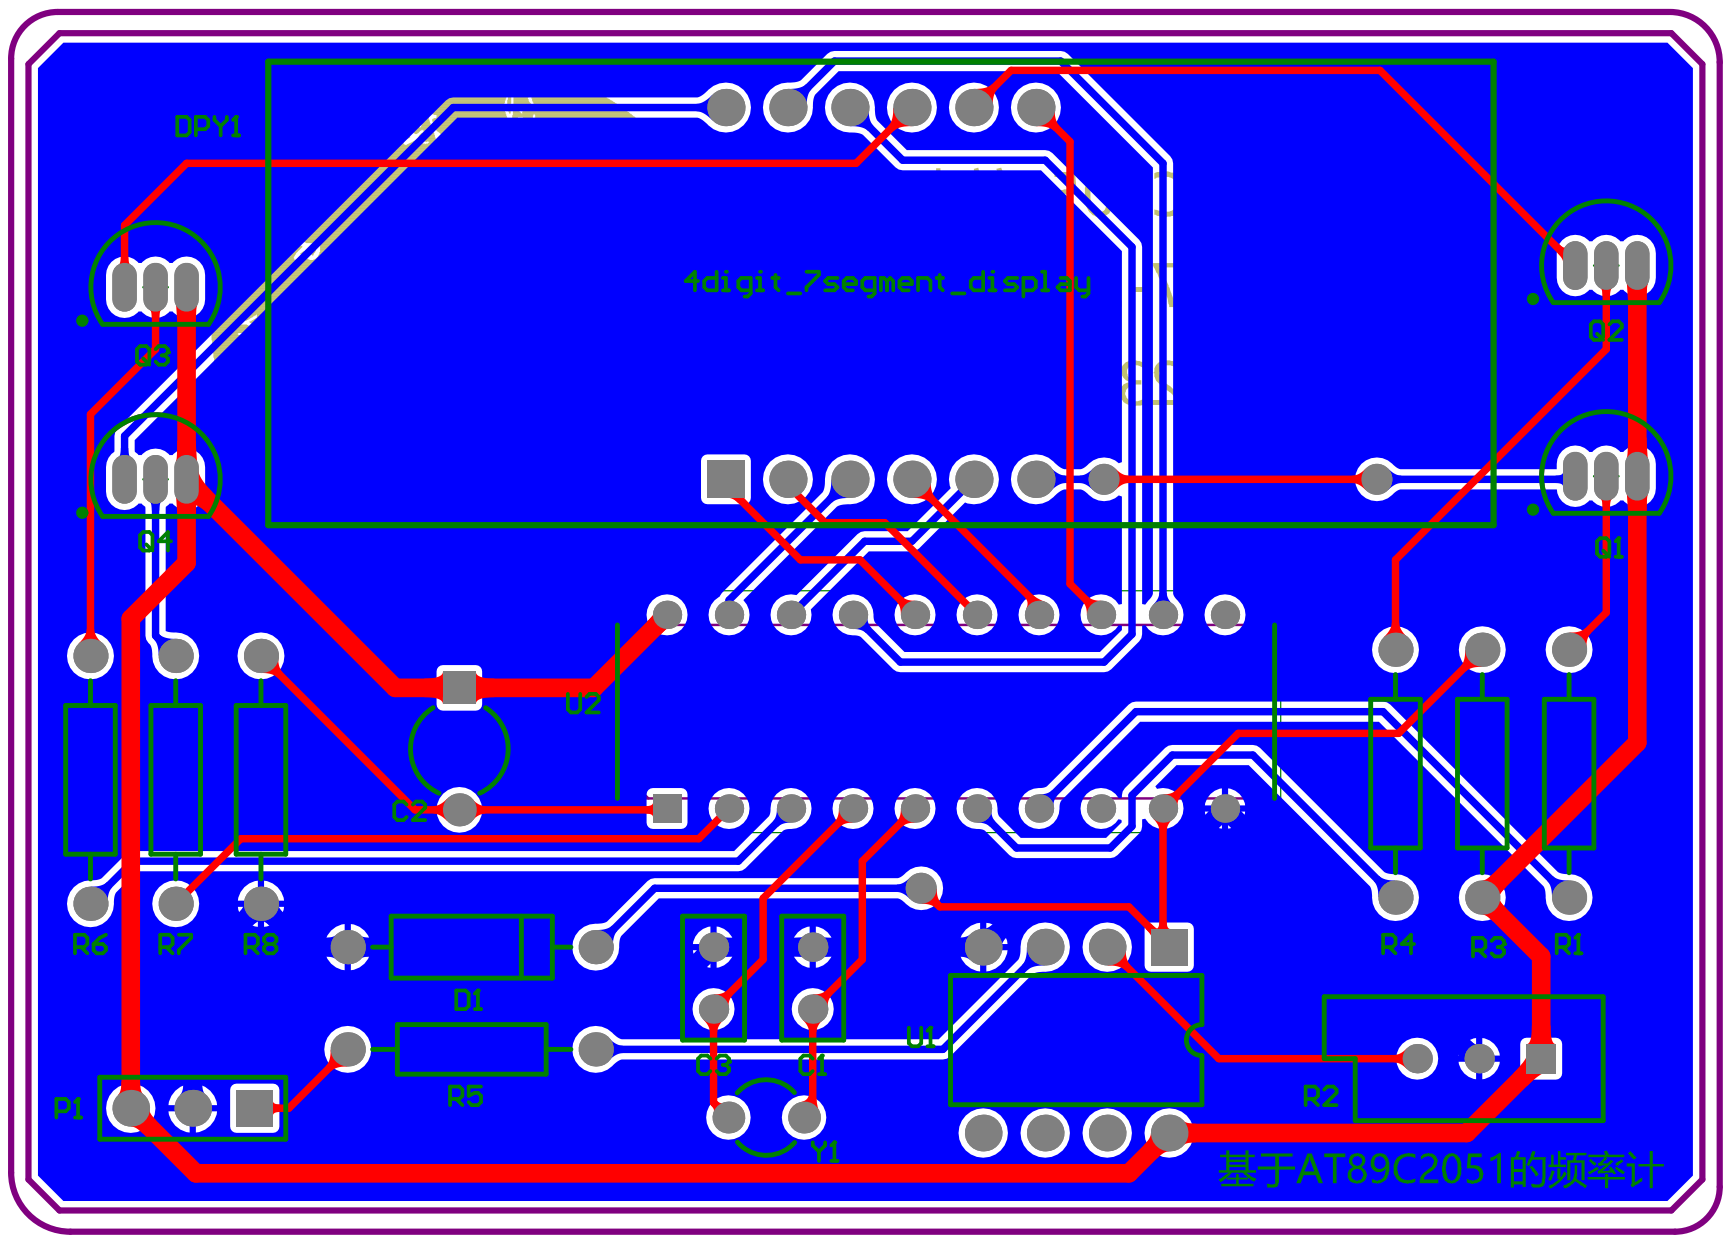
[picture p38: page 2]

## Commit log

2019-11-18 Update Project
    [FrequencyMeter.PrjPcb, FrequencyMeter.SchDoc, SamacSys.PcbLib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]
2019-11-19 Complete schematic drawing
    [FrequencyMeter.PrjPcb, FrequencyMeter.SchDoc]
2019-11-20 Complete PCB Layout
    [FrequencyMeter.PcbDoc, FrequencyMeter.PrjPcb, FrequencyMeter.SchDoc]
2019-11-20 Complete PCB Design
    [FrequencyMeter.PrjPcb]
2019-11-20 Generated Gerber Files
    [FrequencyMeter.GBL, FrequencyMeter.GBO, FrequencyMeter.GBS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]
2019-11-20 Generate Component List
    [FrequencyMeter.PrjPcb, FrequencyMeter.xlsx]
2019-11-23 Update README.md
    更新图片源
2019-11-27 Update README.md
    添加实物展示图
2019-12-04 Update README.md
    更新图片源，解决图片加载失败的问题
2019-12-13 Update Component
    [SamacSys.PcbLib]
